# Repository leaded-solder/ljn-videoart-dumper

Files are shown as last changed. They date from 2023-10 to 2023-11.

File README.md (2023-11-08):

# LJN Video Art cartridge dumper
In 1987, toy company LJN made a home game console called the "[Video Art](https://en.wikipedia.org/wiki/LJN_Video_Art)." It has a handful of games that come on cartridges and is 6805-based.

This repo contains the source for a hardware/software combination to dump these cartridges to ROM files, which can be used in a hypothetical future emulator or clone device.

This device was developed as part of [a Leaded Solder blog](https://www.leadedsolder.com) entry. It cost money and time to develop; if you want to support things like this in the future, please contribute to the Patreon.

## Dumped Games
So far, only one game has been dumped by this device:
 - Disney Story Book

The remaining eight games of the Video Art system have been dumped by others:
 - Video Art Activity Cartridge `ljn_act-1`
 - A Trip to the Zoo `tripzoo`
 - Disney Colouring Book `disneycb`
 - Looney Tunes `looney`
 - Marvel Super-Heroes `marvel`
 - My Dream Day `dreamday`
 - My Favorite Doll `favdoll`
 - On the Move `onmove`

If you have a Video Art cartridge that is not listed here, please get in touch.

## Hardware
### Requirements
You will need:
 - An Arduino Uno or compatible. I used the "Elegoo Uno R3" from Amazon for development and testing;
 - A USB cable;
 - 2x DIP 74HCT595 (74HC595 is probably fine);
 - 1x DIP 74HCT165 (74HC165 is probably fine);
 - The cartridge slot for the LJN cartridge, I used a [TE AMP 5530843-3](https://www.te.com/usa-en/product-5530843-3.html);
 - A length of component leg (e.g. leftover resistor) or some wire;
 - Arduino shield stacking headers (I got mine off Amazon)

### Assembly Instructions
Assembly is a bit tricky, so go shortest to tallest component as you are populating the board. The stacking connectors should go last.

The cartridge connector should be tilted back slightly to make sure there is clearance with the stacking connectors.

Stick a wire or a bent resistor leg through the "0Ω" resistor footprint on the board.

There is no need to populate the two test points TP1 or TP2; these are meant for a beaded test hook, in order to debug the board using a logic probe.

It is challenging to make the stacking connectors go in straight; if you have a better way, please let me know. I used sticky tack/poster putty and bent the pins to mate with the Uno base board.

## Software
### Build instructions
 1. Install Arduino IDE. I developed this with version 2.2.1, but I assume any Arduino editor should work for this purpose.
 2. Open the `.ino` file.
 3. Connect your Arduino Uno (or compatible) to the USB port and upload the firmware to the board. This might require some configuration; check your board vendor for more details.
 4. Insert the cartridge. The label side of the cartridge must face outwards, towards the text on the PCB that says "label side this way."

### Usage instructions
For now, there is no software client for this dumper. Instead, you'll want to use the Serial Monitor from the Arduino IDE.

When the Uno starts up, it should display a message like this:

```
LJN VideoArt ROM Dumper
OE is on pin 10
```

Type `dump` into the text input, press return, and wait for the dump to complete. The monitor should slowly fill with hexadecimal values from the ROM, followed by the message `done.`

Open the `interpreter.py` Python script in your favourite text editor.

Copy and paste the hex values from the Arduino Serial Monitor output into the string `DUMP_STRING`. Make sure none of the old string is there, and make sure it makes a valid Python string (i.e. that it is surrounded by single quotes and is all one line.)

Run the `interpreter.py` Python script. It should generate a file called `rom.bin` that is exactly 16,384 bytes long.

If you know that your ROM is longer than 16,384 bytes, this board may not work for you. Please contact me immediately and we'll work something out.

### Other Commands
Not many commands are supported; this list is here for mostly diagnostic purposes.

| Command | Does what? |
|---|---|
| `dump`  | Dumps a 16K ROM |
| `info`  | Version identification for the firmware. |
| `oelo`  | Pulls the output-enable line of the cartridge LOW (enabled) |
| `oehi`  | Pulls the output-enable line of the cartridge HIGH (disabled) |

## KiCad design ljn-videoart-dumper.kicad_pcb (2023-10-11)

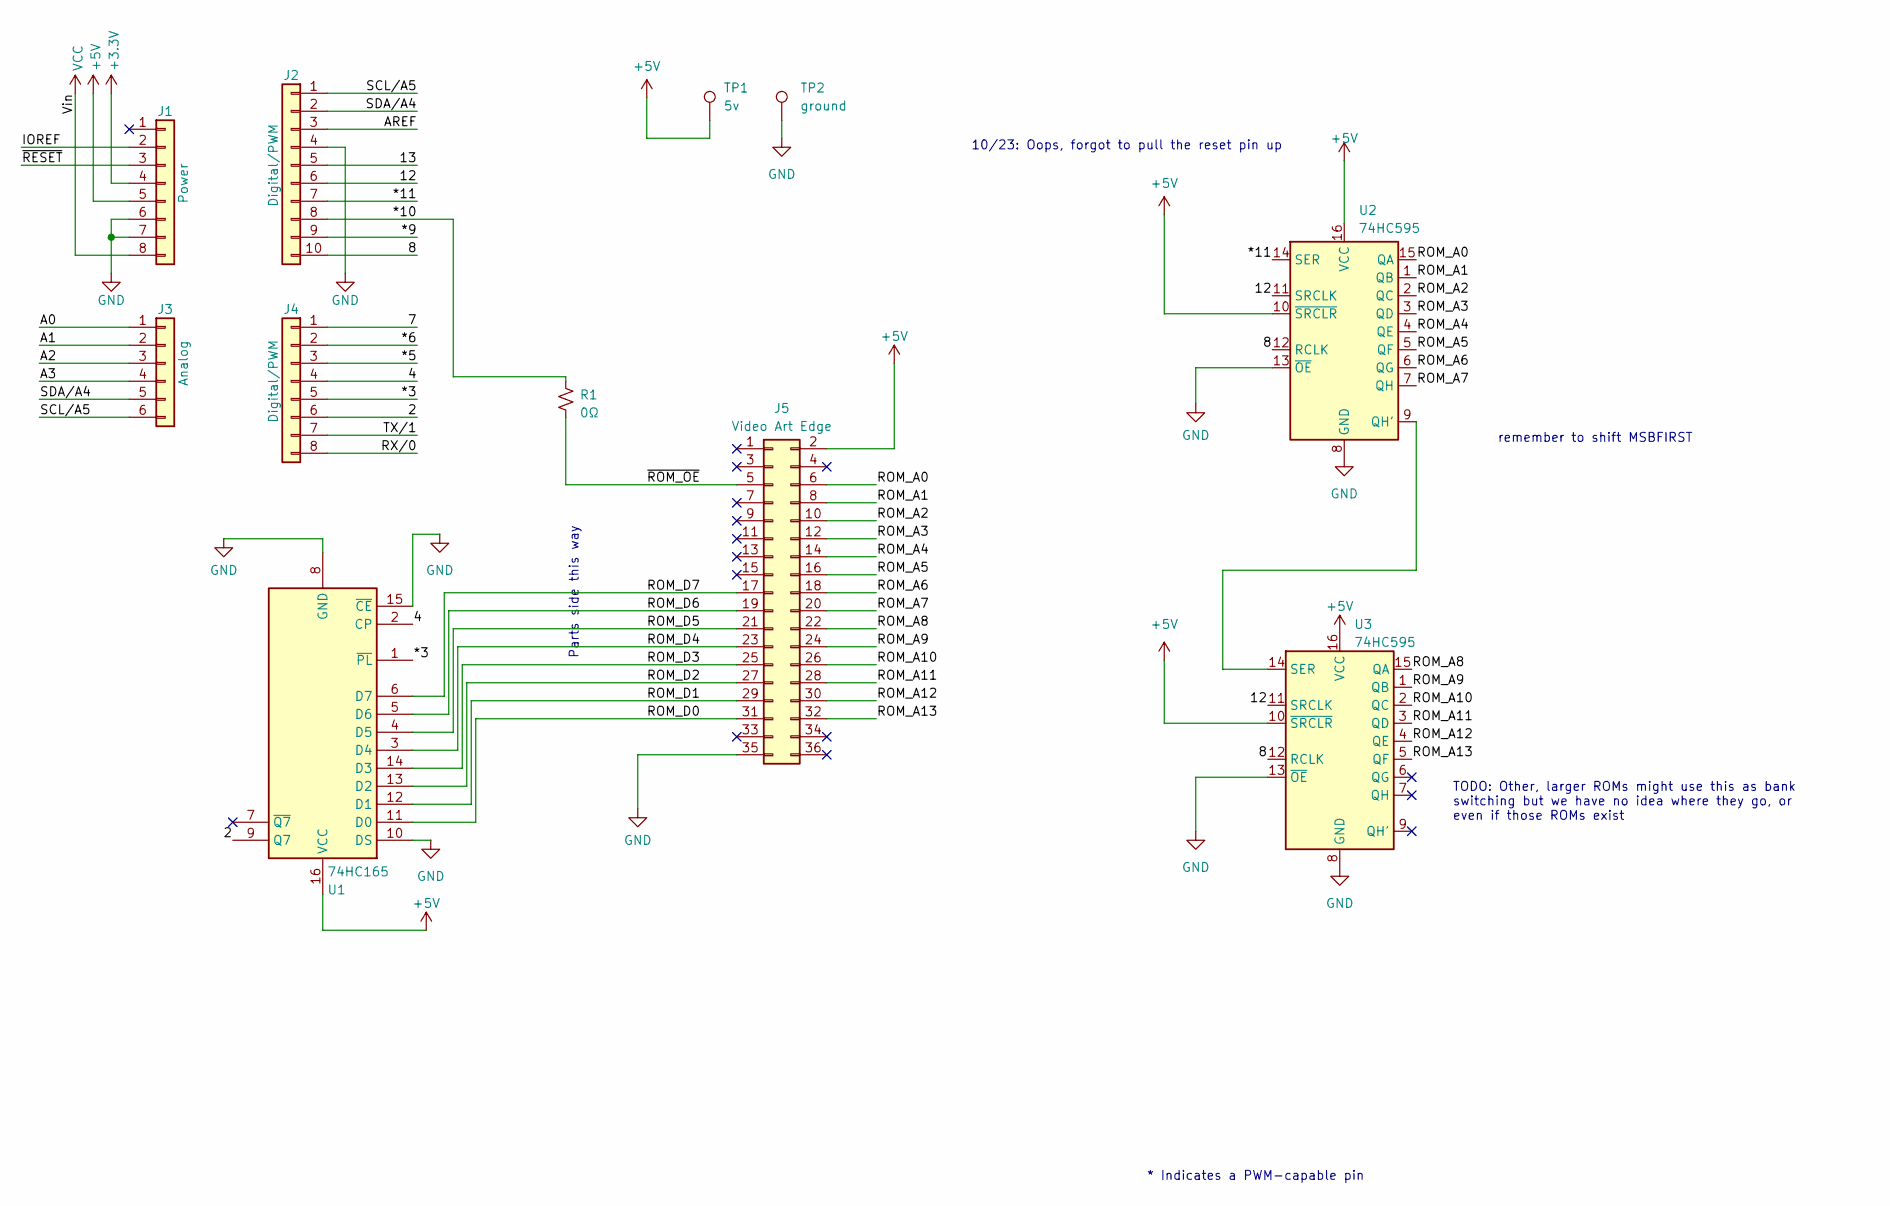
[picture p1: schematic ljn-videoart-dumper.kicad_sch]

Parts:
J1: Power; PinSocket_1x08_P2.54mm_Vertical
J2: Digital/PWM; PinSocket_1x10_P2.54mm_Vertical
J3: Analog; PinSocket_1x06_P2.54mm_Vertical
J4: Digital/PWM; PinSocket_1x08_P2.54mm_Vertical
J5: Video Art Edge; CONN_5530843-3_TYC
R1: 0Ω; R_Axial_DIN0207_L6.3mm_D2.5mm_P10.16mm_Horizontal
TP1: 5v; TestPoint_Loop_D2.54mm_Drill1.5mm_Beaded
TP2: ground; TestPoint_Loop_D2.54mm_Drill1.5mm_Beaded
U1: 74HC165; DIP-16_W7.62mm_Socket_LongPads
U2, U3: 74HC595; DIP-16_W7.62mm_Socket_LongPads

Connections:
+3V3: J1.4
+5V: J1.5, J5.2, TP1.1, U1.16 (VCC), U2.10 (~SRCLR), U2.16 (VCC), U3.10 (~SRCLR), U3.16 (VCC)
/2: J4.6, U1.9 (Q7)
/4: J4.4, U1.2 (CP)
/7: J4.1
/8: J2.10, U2.12 (RCLK), U3.12 (RCLK)
/12: J2.6, U2.11 (SRCLK), U3.11 (SRCLK)
/13: J2.5
/*3: J4.5, U1.1 (~PL)
/*5: J4.3
/*6: J4.2
/*9: J2.9
/*10: J2.8, R1.1
/*11: J2.7, U2.14 (SER)
/A0: J3.1
/A1: J3.2
/A2: J3.3
/A3: J3.4
/AREF: J2.3
/IOREF: J1.2
/ROM_A0: J5.6, U2.15 (QA)
/ROM_A1: J5.8, U2.1 (QB)
/ROM_A2: J5.10, U2.2 (QC)
/ROM_A3: J5.12, U2.3 (QD)
/ROM_A4: J5.14, U2.4 (QE)
/ROM_A5: J5.16, U2.5 (QF)
/ROM_A6: J5.18, U2.6 (QG)
/ROM_A7: J5.20, U2.7 (QH)
/ROM_A8: J5.22, U3.15 (QA)
/ROM_A9: J5.24, U3.1 (QB)
/ROM_A10: J5.26, U3.2 (QC)
/ROM_A11: J5.28, U3.3 (QD)
/ROM_A12: J5.30, U3.4 (QE)
/ROM_A13: J5.32, U3.5 (QF)
/ROM_D0: J5.31, U1.11 (D0)
/ROM_D1: J5.29, U1.12 (D1)
/ROM_D2: J5.27, U1.13 (D2)
/ROM_D3: J5.25, U1.14 (D3)
/ROM_D4: J5.23, U1.3 (D4)
/ROM_D5: J5.21, U1.4 (D5)
/ROM_D6: J5.19, U1.5 (D6)
/ROM_D7: J5.17, U1.6 (D7)
/RX/0: J4.8
/SCL/A5: J2.1, J3.6
/SDA/A4: J2.2, J3.5
/TX/1: J4.7
/~RESET: J1.3
/~ROM_OE: J5.5, R1.2
GND: J1.6, J1.7, J2.4, J5.35, TP2.1, U1.8 (GND), U1.10 (DS), U1.15 (~CE), U2.8 (GND), U2.13 (~OE), U3.8 (GND), U3.13 (~OE)
unnamed: U2.9 (QH'), U3.14 (SER)
VCC: J1.8

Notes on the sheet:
remember to shift MSBFIRST
TODO: Other, larger ROMs might use this as bank switching but we have no idea where they go, or even if those ROMs exist
10/23: Oops, forgot to pull the reset pin up
* Indicates a PWM-capable pin
Parts side this way

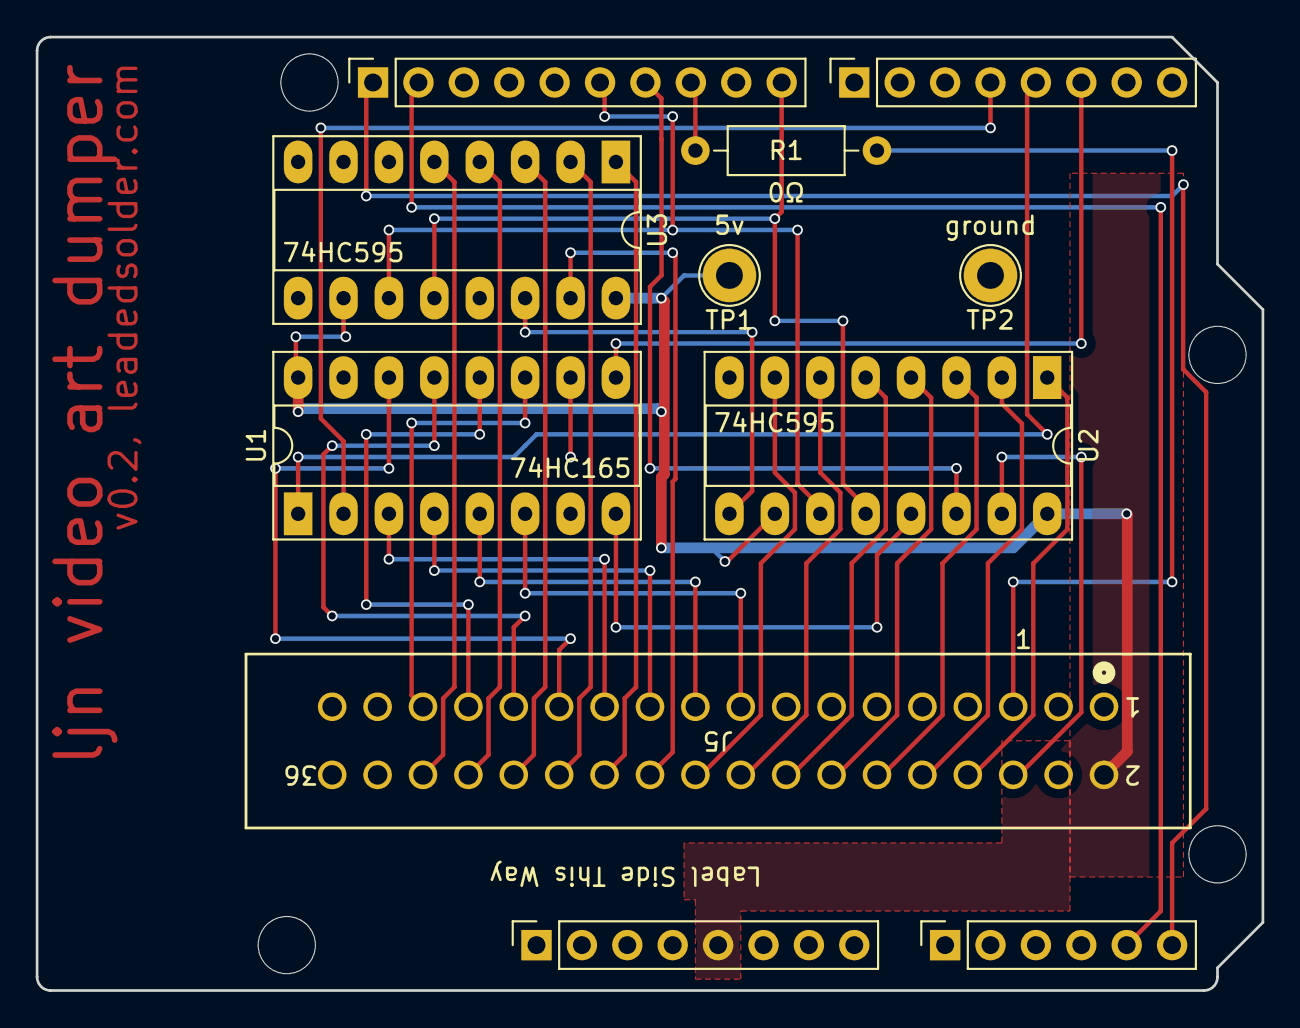
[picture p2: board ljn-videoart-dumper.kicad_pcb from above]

Board: 2 copper layers, 68.6 x 53.3 mm, 15 parts (0 on the bottom side), 35 nets.

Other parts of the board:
MH1, MH2, MH3, MH4: MountingHole_3.2mm

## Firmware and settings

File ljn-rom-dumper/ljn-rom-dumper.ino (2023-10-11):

/**
  LJN Video Art cartridge dumper
  Driver firmware to run the cartridge dumping process for a Video Art cartridge

  GNU GPL licensed by leadedsolder.com, 2023
*/

const uint16_t ROM_LENGTH = 16 * 1024;  // 16K ROM assumed (LH2326xx), change this if yours is bigger/smaller

const uint8_t PIN_ROM_OE = 10;

// 74HCT165 to read data bus from cartridge
const uint8_t PIN_DATA_CLOCK = 4;
const uint8_t PIN_DATA_LATCH = 3;
const uint8_t PIN_DATA_DATA = 2;  // Q7

// 74HCT595s to set address bus on cartridge
const uint8_t PIN_ADDRESS_STORAGE_CLK = 8;  // RCLK
const uint8_t PIN_ADDRESS_SHIFT_CLK = 12;   // SRCLK
const uint8_t PIN_ADDRESS_DATA = 11;        // SERial data

void setup() {
  Serial.begin(38400);
  Serial.println("LJN VideoArt ROM Dumper");
  Serial.print("OE is on pin ");
  Serial.println(PIN_ROM_OE);

  pinMode(PIN_ROM_OE, OUTPUT);
  digitalWrite(PIN_ROM_OE, HIGH);

  pinMode(PIN_DATA_DATA, INPUT);
  pinMode(PIN_DATA_LATCH, OUTPUT);
  digitalWrite(PIN_DATA_LATCH, HIGH);
  pinMode(PIN_DATA_CLOCK, OUTPUT);
  digitalWrite(PIN_DATA_CLOCK, LOW);

  pinMode(PIN_ADDRESS_SHIFT_CLK, OUTPUT);
  digitalWrite(PIN_ADDRESS_SHIFT_CLK, LOW);
  pinMode(PIN_ADDRESS_STORAGE_CLK, OUTPUT);
  digitalWrite(PIN_ADDRESS_STORAGE_CLK, LOW);
  pinMode(PIN_ADDRESS_DATA, OUTPUT);
  digitalWrite(PIN_ADDRESS_DATA, LOW);
}

void setOutputEnable(bool isEnabled) {
  // Confirmed active low
  digitalWrite(PIN_ROM_OE, isEnabled ? LOW : HIGH);
}

void assertAddressBus(uint16_t address) {
  digitalWrite(PIN_ADDRESS_STORAGE_CLK, LOW);  // prepare to receive

  // high byte
  shiftOut(PIN_ADDRESS_DATA, PIN_ADDRESS_SHIFT_CLK, MSBFIRST, (address >> 8));
  // low byte
  shiftOut(PIN_ADDRESS_DATA, PIN_ADDRESS_SHIFT_CLK, MSBFIRST, address);

  digitalWrite(PIN_ADDRESS_STORAGE_CLK, HIGH);  // latch it
}

uint8_t shiftIn165(uint8_t dataPin, uint8_t clockPin, uint8_t bitOrder) {
  uint8_t value = 0;
  uint8_t i;

  for (i = 0; i < 8; ++i) {
    digitalWrite(clockPin, LOW);
    if (bitOrder == LSBFIRST) {
      value |= digitalRead(dataPin) << i;
    } else {
      value |= digitalRead(dataPin) << (7 - i);
    }
    digitalWrite(clockPin, HIGH);
    delayMicroseconds(20);
  }
  return value;
}

uint8_t clockOutData() {
  // Read the data on the data bus, assuming that
  // the output enable is already prepared
  digitalWrite(PIN_DATA_LATCH, LOW);  // load into shift register
  delayMicroseconds(50);
  digitalWrite(PIN_DATA_LATCH, HIGH);  // stop loading into shift register

  // Read out the data from the shift register
  uint8_t result = shiftIn165(PIN_DATA_DATA, PIN_DATA_CLOCK, MSBFIRST);

  return result;
}

void dumpCartridgeToSerial() {
  uint16_t address = 0;
  while (address < ROM_LENGTH) {  // HACK just for now
    setOutputEnable(true);  // enabled
    delayMicroseconds(50); // wait for ROM to put stuff on the wire
    assertAddressBus(address);
    delayMicroseconds(50); // wait for ROM to put stuff on the wire

    byte result = clockOutData();
    Serial.print(result, HEX);
    Serial.print(' ');

    setOutputEnable(false);  // disabled

    ++address;
  }
}

void loop() {
  // This interface will eventually become deprecated when I do a client program?

  String commandLine = "";
  if (Serial.available()) {
    commandLine = Serial.readStringUntil('\n');
    if (commandLine.equalsIgnoreCase("dump")) {
      dumpCartridgeToSerial();
      Serial.println("");
      Serial.println("done.");
    } else if (commandLine.equalsIgnoreCase("info")) {
      Serial.println("Version 1");
    } else if (commandLine.equalsIgnoreCase("oelo")) {
      digitalWrite(PIN_ROM_OE, LOW);
    } else if (commandLine.equalsIgnoreCase("oehi")) {
      digitalWrite(PIN_ROM_OE, HIGH);
    } else {
      String error = "Unknown command '";
      error.concat(commandLine);
      error.concat("'");
      Serial.println(error);
    }
  }
}

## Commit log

2023-05-31 Pinout of cartridge edge
    [ljn-videoart-dumper.kicad_pcb, ljn-videoart-dumper.kicad_sch]
2023-06-02 Add connector
    [ljn-videoart-dumper.kicad_pcb, ljn-videoart-dumper.kicad_sch]
2023-06-02 Fix pin numbering before it gets embarrassing
    [ljn-videoart-dumper.kicad_pcb, ljn-videoart-dumper.kicad_sch]
2023-06-02 Final re-route
    [ljn-videoart-dumper.kicad_pcb, ljn-videoart-dumper.kicad_sch]
2023-06-02 V1 released to JLCPCB
    [ljn-videoart-dumper.kicad_pcb]
2023-06-02 not sure why plot didn't include edge.cuts or silk, but fixed now
    [ljn-videoart-dumper.kicad_pcb]
2023-06-17 Untested Arduino firmware
2023-06-20 Nothing I'm doing with address pins seems to matter?
    [ljn-videoart-dumper.kicad_sch]
2023-07-05 Move everything away from the USB-port
    [ljn-videoart-dumper.kicad_pcb]
2023-07-05 Fix cart slot labels
    [ljn-videoart-dumper.kicad_pcb]
2023-07-05 0-ohm label
    [ljn-videoart-dumper.kicad_pcb]
2023-10-10 Fix errors, add 5v/gnd test points
    [ljn-videoart-dumper.kicad_pcb, ljn-videoart-dumper.kicad_sch]
2023-10-10 5v/gnd markings
    [ljn-videoart-dumper.kicad_pcb]
2023-10-10 Messing with labels
    [ljn-videoart-dumper.kicad_pcb]
2023-10-11 Short MR to 5V
    [ljn-videoart-dumper.kicad_pcb, ljn-videoart-dumper.kicad_sch]
2023-10-11 Confirmed MSBFIRST is correct
    [ljn-rom-dumper.ino]
